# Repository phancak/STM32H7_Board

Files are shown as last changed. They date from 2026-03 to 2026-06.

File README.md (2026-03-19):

# STM32H7S3 High-Performance Modular Compute Platform

<div align="center">
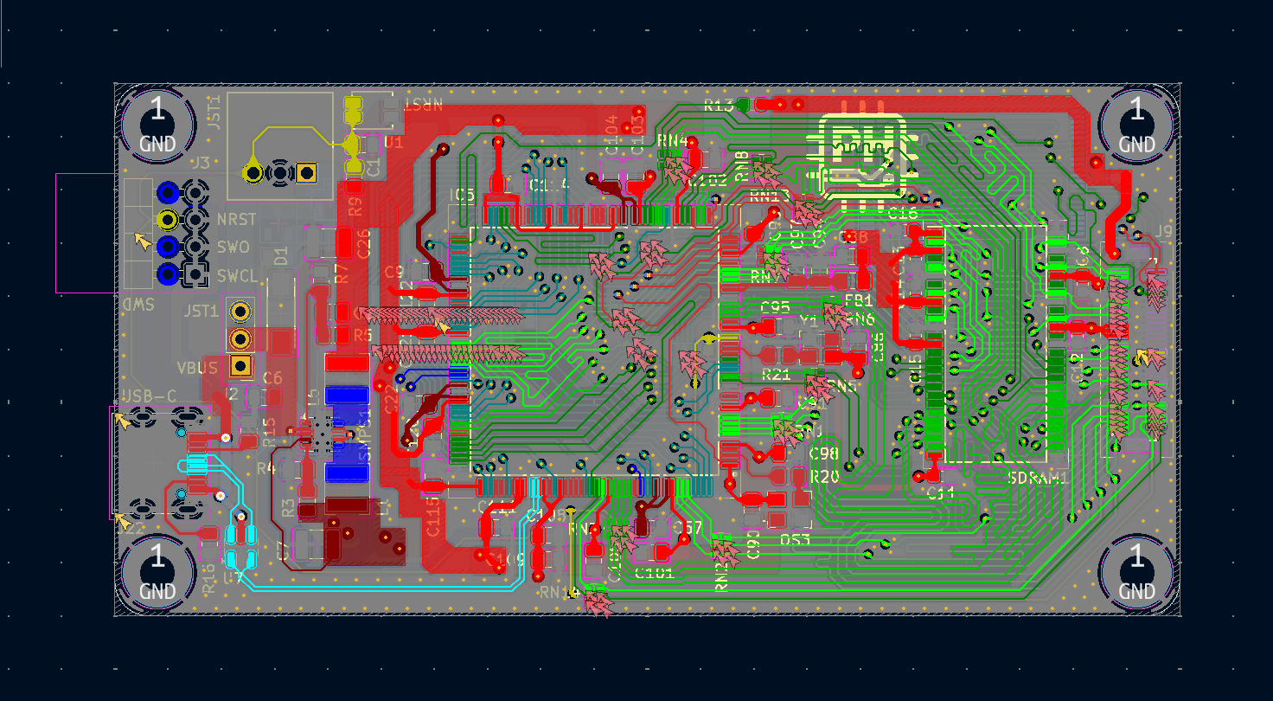
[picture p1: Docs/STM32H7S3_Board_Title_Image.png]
STM32H7S3 PCB 3D Render
  
  <br>
  <em>4-layer PCB diagram.</em>
</div>





## 📑 Quick Access
* [**📂 View Project Schematics (PDF)**](./Schematics/STM32H7_Board_Schematics.pdf)

## 📌 Project Overview
This project features a professional-grade, high-speed embedded system centered around the **STM32H7S3I8T6** (ARM Cortex-M7 running at 600 MHz). Developed as a post-graduate technical showcase, this board demonstrates proficiency in high-speed digital design, complex memory interfacing (SDRAM/NAND), and modular system architecture.

The platform is designed to serve as a high-bandwidth "Main Compute Module" that interfaces with expansion boards via a variety of industrial-standard protocols (PSSI, I2S, I2C, SPI, UART).

## 🛠 Technical Specifications

### Core Processing & Memory
* **MCU:** STM32H7S3I8T6 (600 MHz, 1MB SRAM, advanced security and graphics acceleration).
* **SDRAM:** 256 Mbit (IS42S83200J) @ 166 MHz — utilized for high-speed frame buffering and large-scale data processing.
* **NAND Flash:** 2 Gbit (MT29F2G08) — providing robust, non-volatile storage for OS and data logging.

### Connectivity & Expansion
* **PSSI (Parallel Synchronous Slave Interface):** Dedicated high-speed parallel bus for camera or FPGA data acquisition.
* **Audio (I2S):** High-fidelity audio interface with dedicated Master Clock (MCK) routing.
* **USB-C OTG:** High-speed (480 Mbps) data support with integrated UCPD (USB-C Power Delivery) logic.
* **Peripheral Bus:** Fully broken-out I2C, SPI, and UART headers for modular hardware stacking.

## 🚀 Engineering Design Highlights

### 1. High-Speed Signal Integrity (SI)
* **4-Layer Stackup:** Designed with a dedicated Ground plane (L2) and Power plane (L3) to provide a stable reference and minimize return path inductance.
* **Impedance Control:** Managed 90Ω differential pairs for USB High-Speed and 50Ω single-ended traces for memory clocks.
* **Memory Routing:** Implemented length-matching and fly-by/star topology considerations for the SDRAM address and data bus to meet strict setup and hold time requirements at 166 MHz.

### 2. Power Delivery Network (PDN)
* **Core Stability:** Designed for the 600 MHz switching transients of the Cortex-M7 using low-ESR ceramic decoupling arrays.
* **Via Stitching:** Utilized parallel via strategies (e.g., dual 0.3mm vias) for high-current power paths to minimize IR drop and parasitic inductance.

### 3. Hardware Robustness
* **ESD Protection:** Integrated low-capacitance TVS diode arrays on USB-C lines to protect sensitive MCU transceivers.
* **Signal Conditioning:** Series termination resistors on high-speed clocks (MCK, CK) and proper pull-up configurations for Open-Drain lines (NAND_RB).

## 🔬 Testing & Validation Plan

To ensure the reliability of a 600 MHz system, the following hardware validation protocols were implemented:

### 1. Signal Integrity (SI) Verification
Using a high-bandwidth digital oscilloscope (2 GHz+), the following critical signals are probed to verify timing margins and signal quality:
* **SDRAM Clock (166 MHz):** Measured for overshoot, undershoot, and rise/fall times ($t_R/t_F$) to ensure compliance with the IS42S83200J datasheet. 
* **Eye Diagram Analysis:** Performed on the USB High-Speed (480 Mbps) differential pairs to validate the $90\Omega$ impedance matching and ensure zero bit errors.
* **Clock Jitter:** Measured the stability of the I2S Master Clock (MCK) to prevent phase noise in audio reconstruction.

### 2. Power Integrity (PI) & Thermal Analysis
* **DC Load Testing:** Verified the 3.3V and 1.1V rails under maximum CPU/SDRAM load to ensure the IR drop across the power plane remains within $\pm 3\%$.
* **Transient Response:** Observed the $V_{CORE}$ rail during high-frequency switching to validate the effectiveness of the decoupling capacitor network.
* **Thermal Imaging:** Monitored the STM32H7S3 and SDRAM during continuous burst transfers to identify potential hotspots on the 4-layer stackup.

### 3. Memory Interface Stress Testing
* **MemTest86-style Routines:** Implemented custom firmware to perform pseudo-random pattern writes/reads across the entire 256 Mbit SDRAM space to check for bit-flip errors caused by crosstalk or timing skew.
* **NAND Bad Block Management:** Validated the ECC (Error Correction Code) and wear-leveling logic within the MT29F2G08 driver.

## 🛠 Skills Demonstrated
* **Hardware:** High-speed PCB design (Altium/KiCad), Differential Pair Routing, PDN Optimization, ESD/EMI protection.
* **Firmware:** C/C++, STM32 CubeHAL, Memory Management Units (MMU), DMA configuration.
* **Tools:** Digital Oscilloscopes, Logic Analyzers, Spectrum Analyzers.

## 📂 Repository Structure
* `/Hardware`: Schematic (PDF/Source), PCB Layout, and Layer Stackup definitions.
* `/Firmware`: BSP (Board Support Package), memory initialization code, and driver implementations.
* `/Docs`: Power budget analysis and timing margin calculations.

## 🎓 About the Author
I am a recent **Electrical Engineering graduate from the University of British Columbia (UBC)**. This project represents my ability to transition theoretical academic knowledge into a complex, manufacturable high-speed digital system.

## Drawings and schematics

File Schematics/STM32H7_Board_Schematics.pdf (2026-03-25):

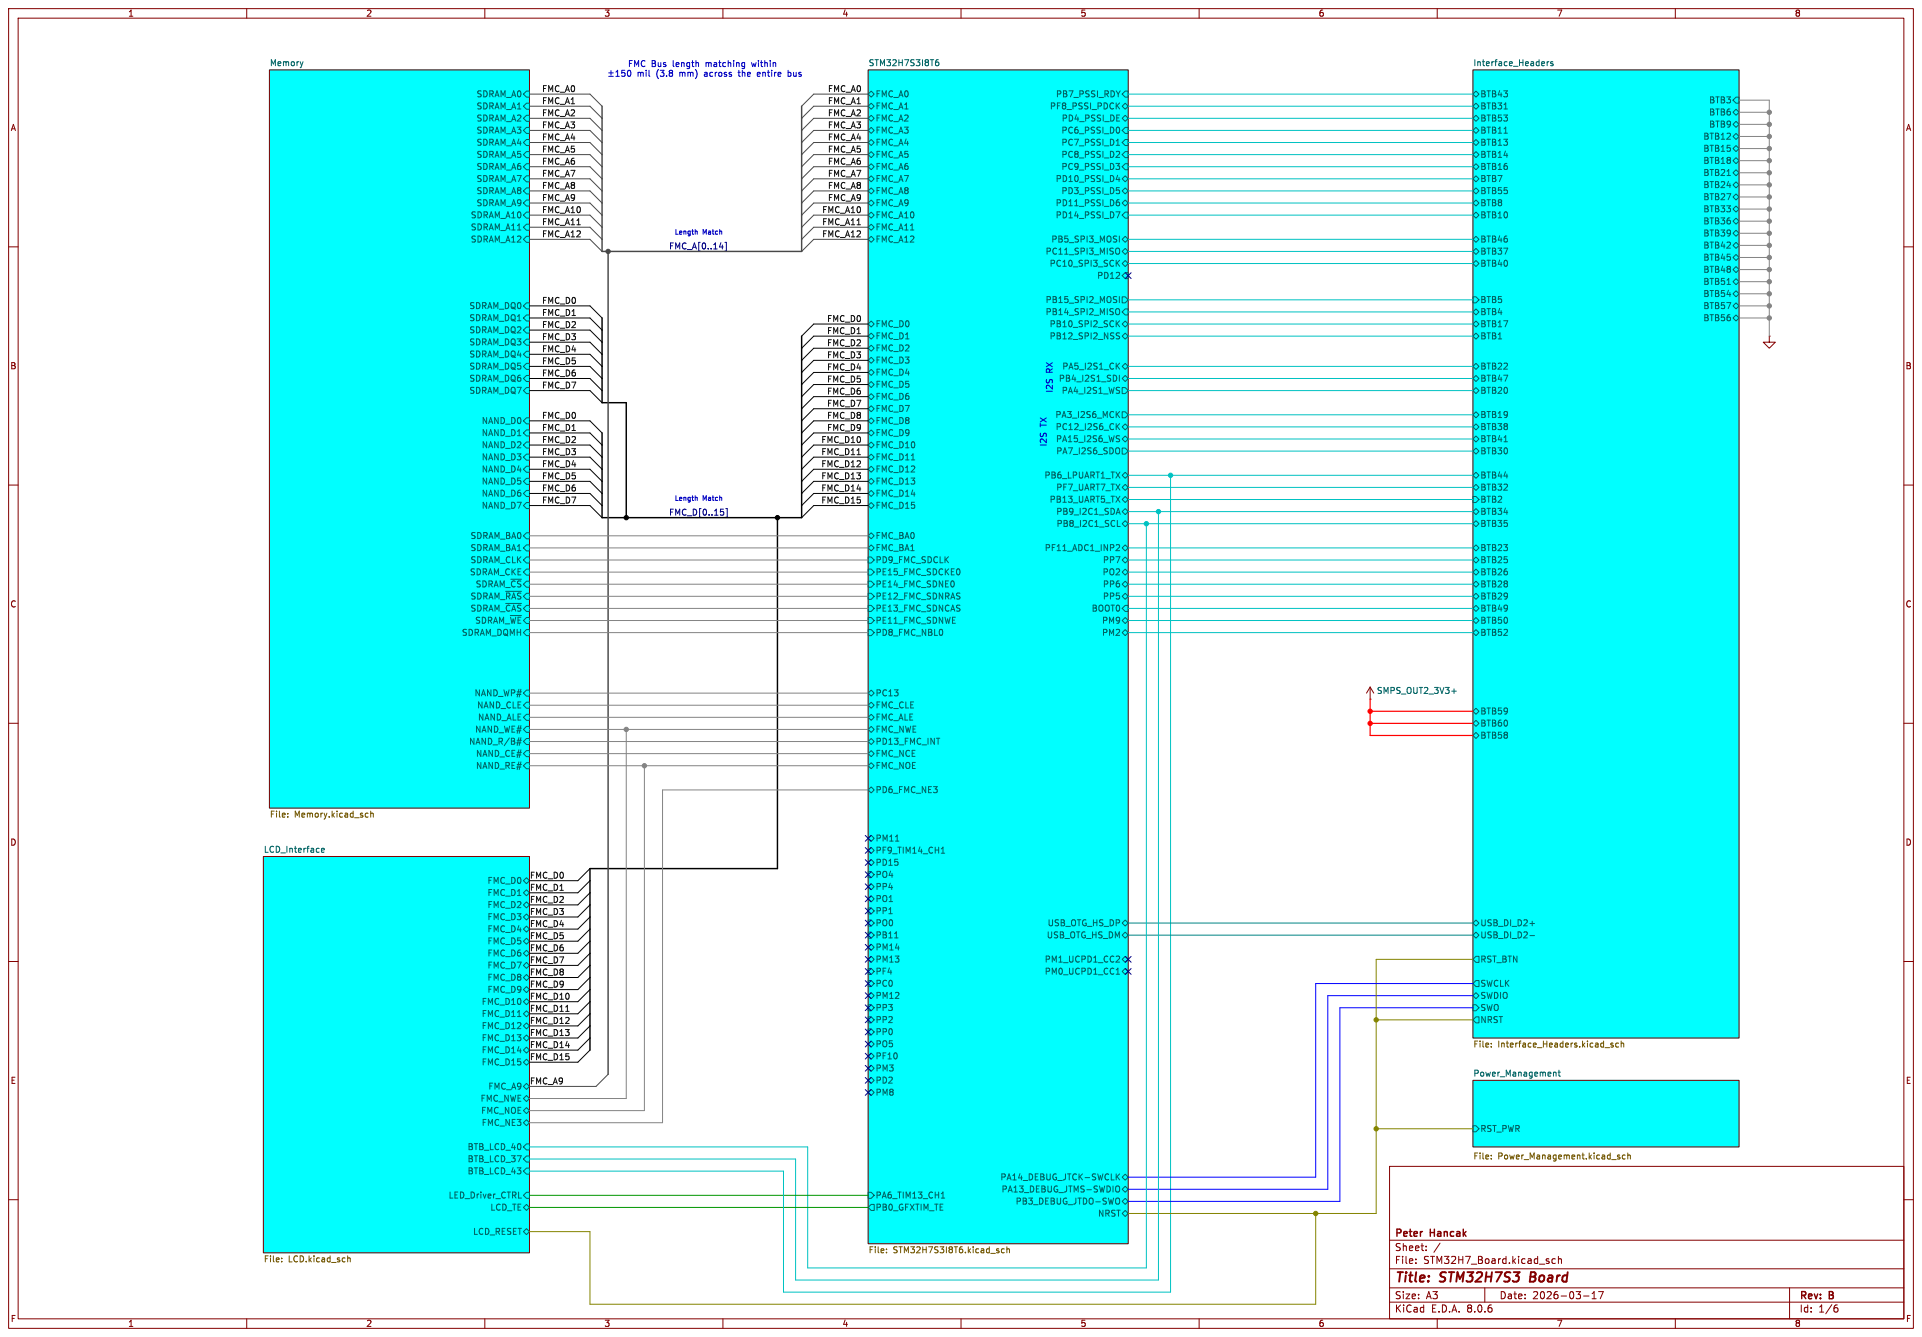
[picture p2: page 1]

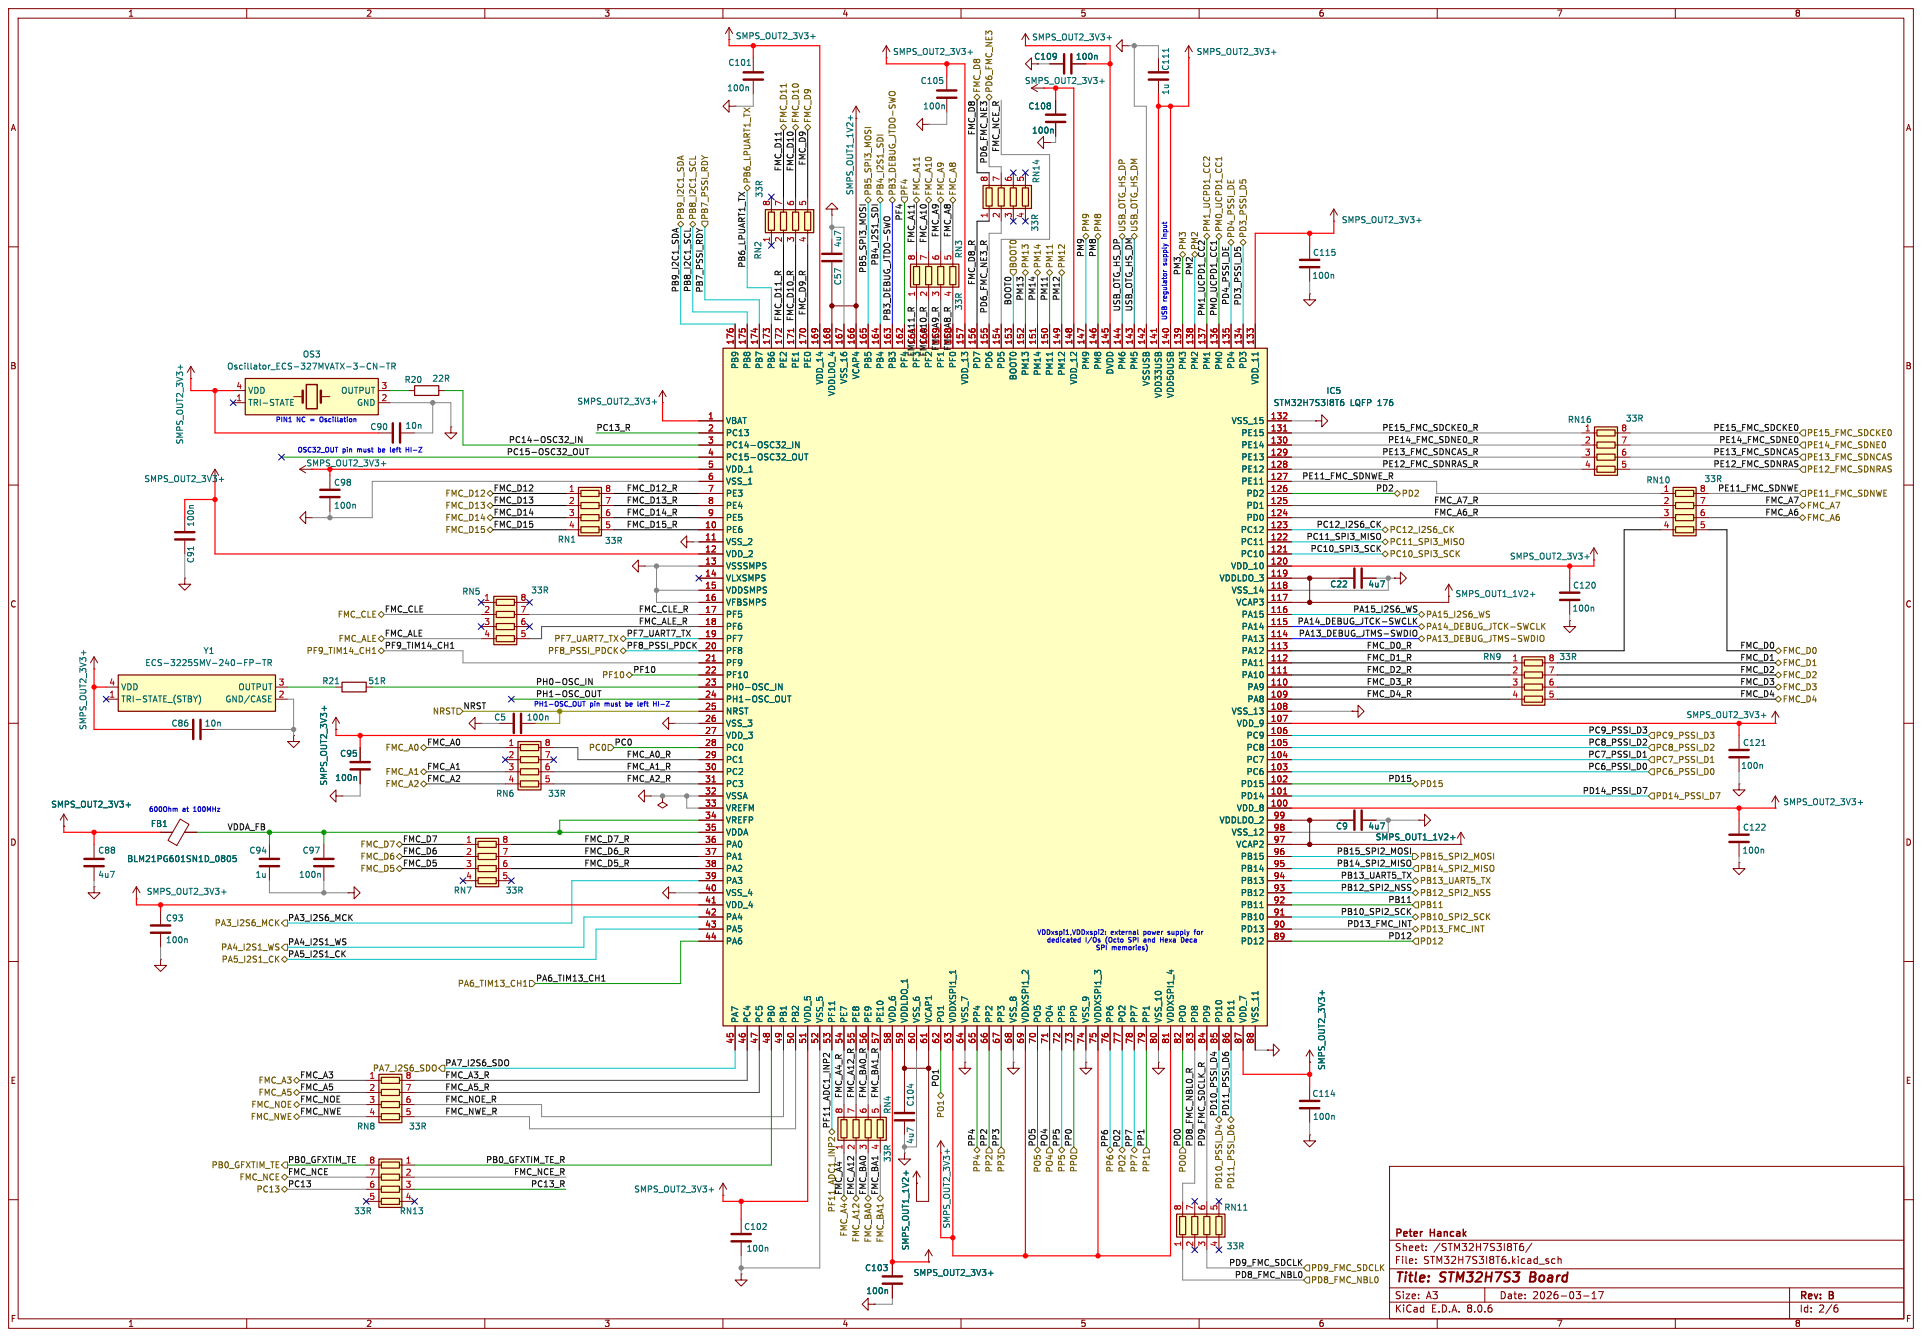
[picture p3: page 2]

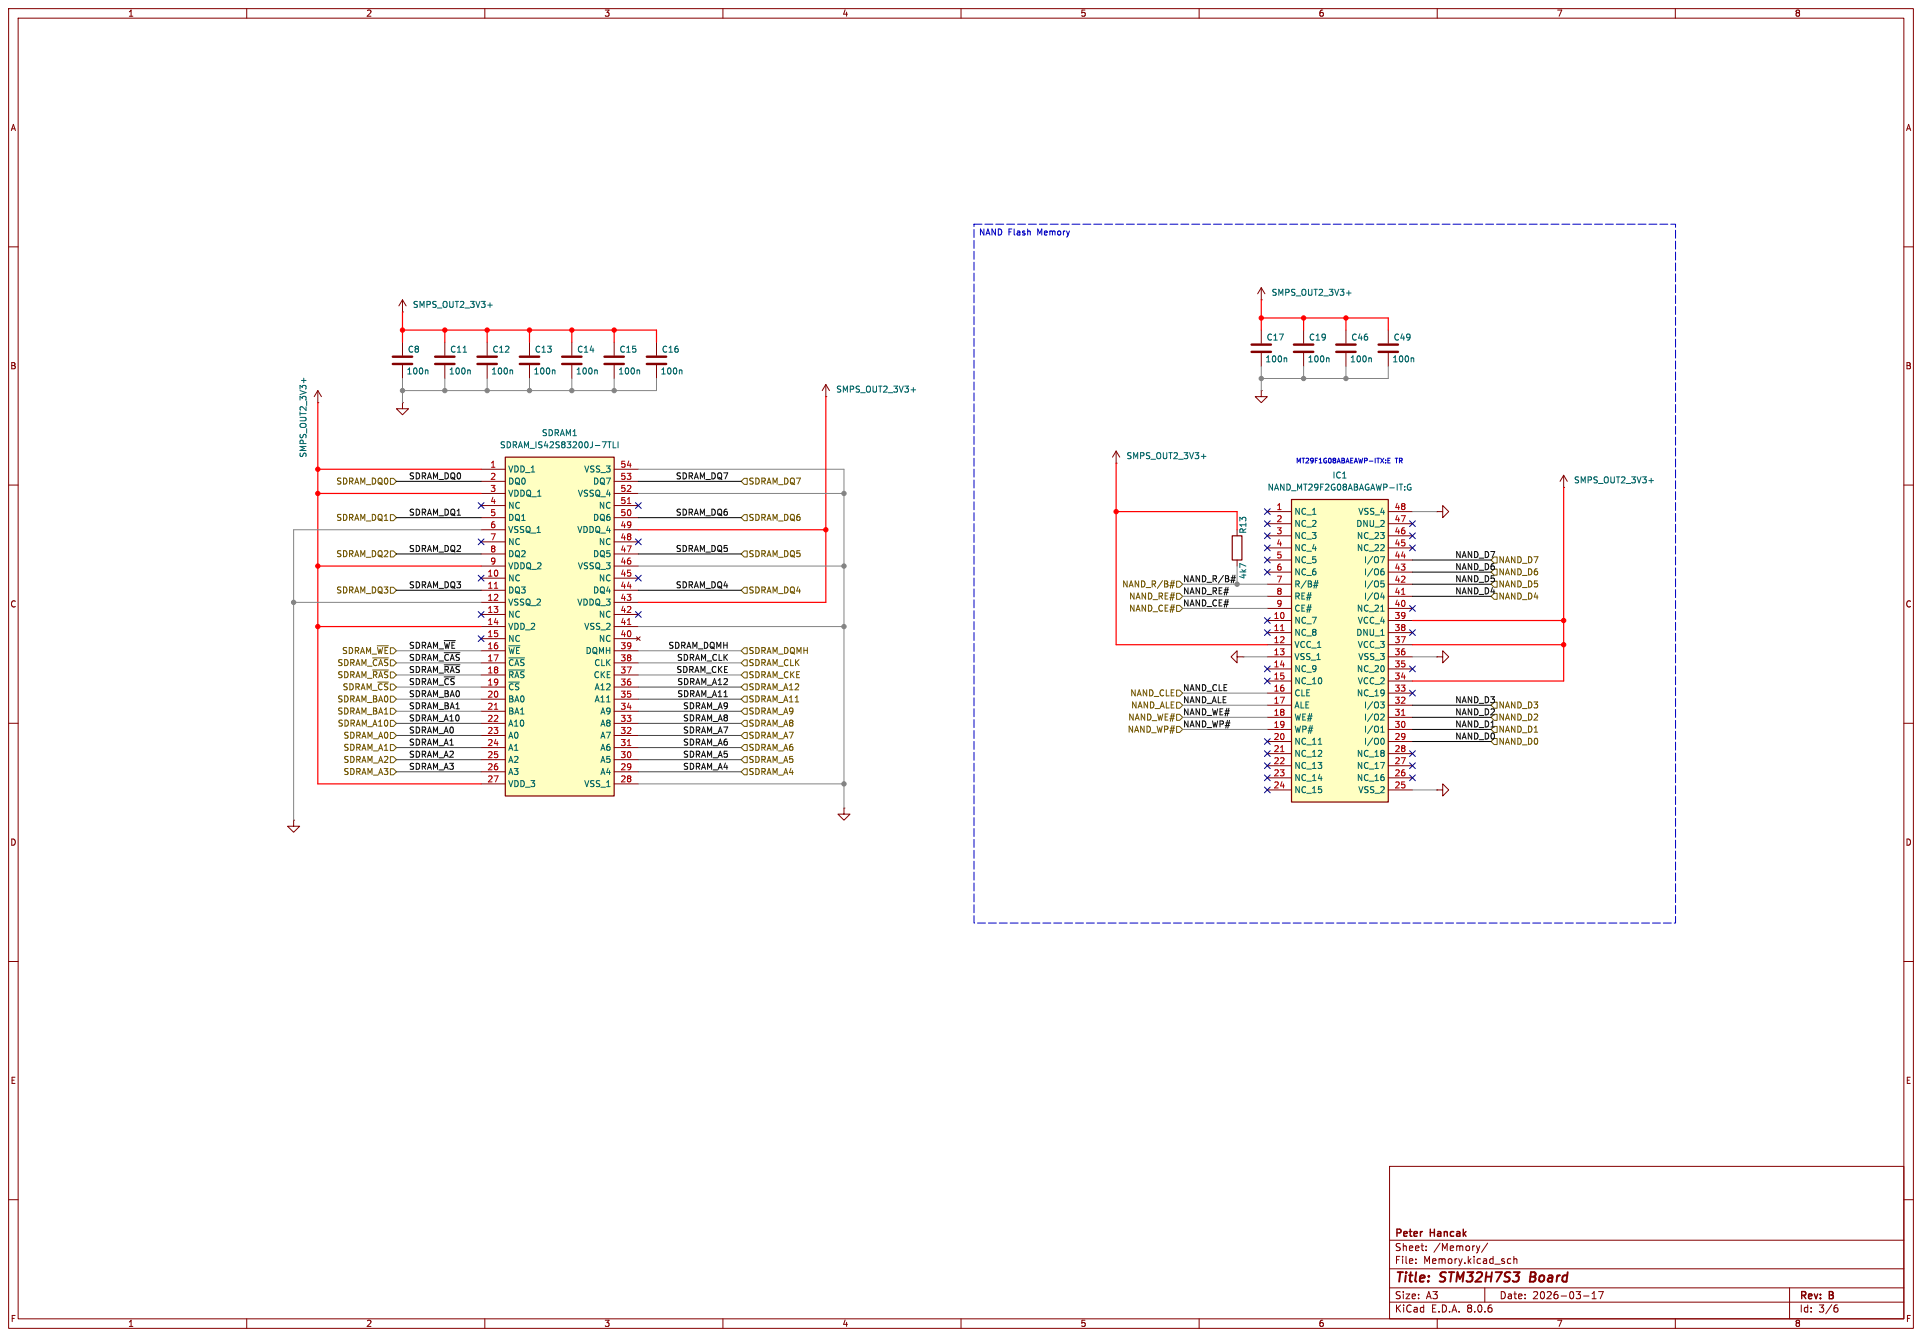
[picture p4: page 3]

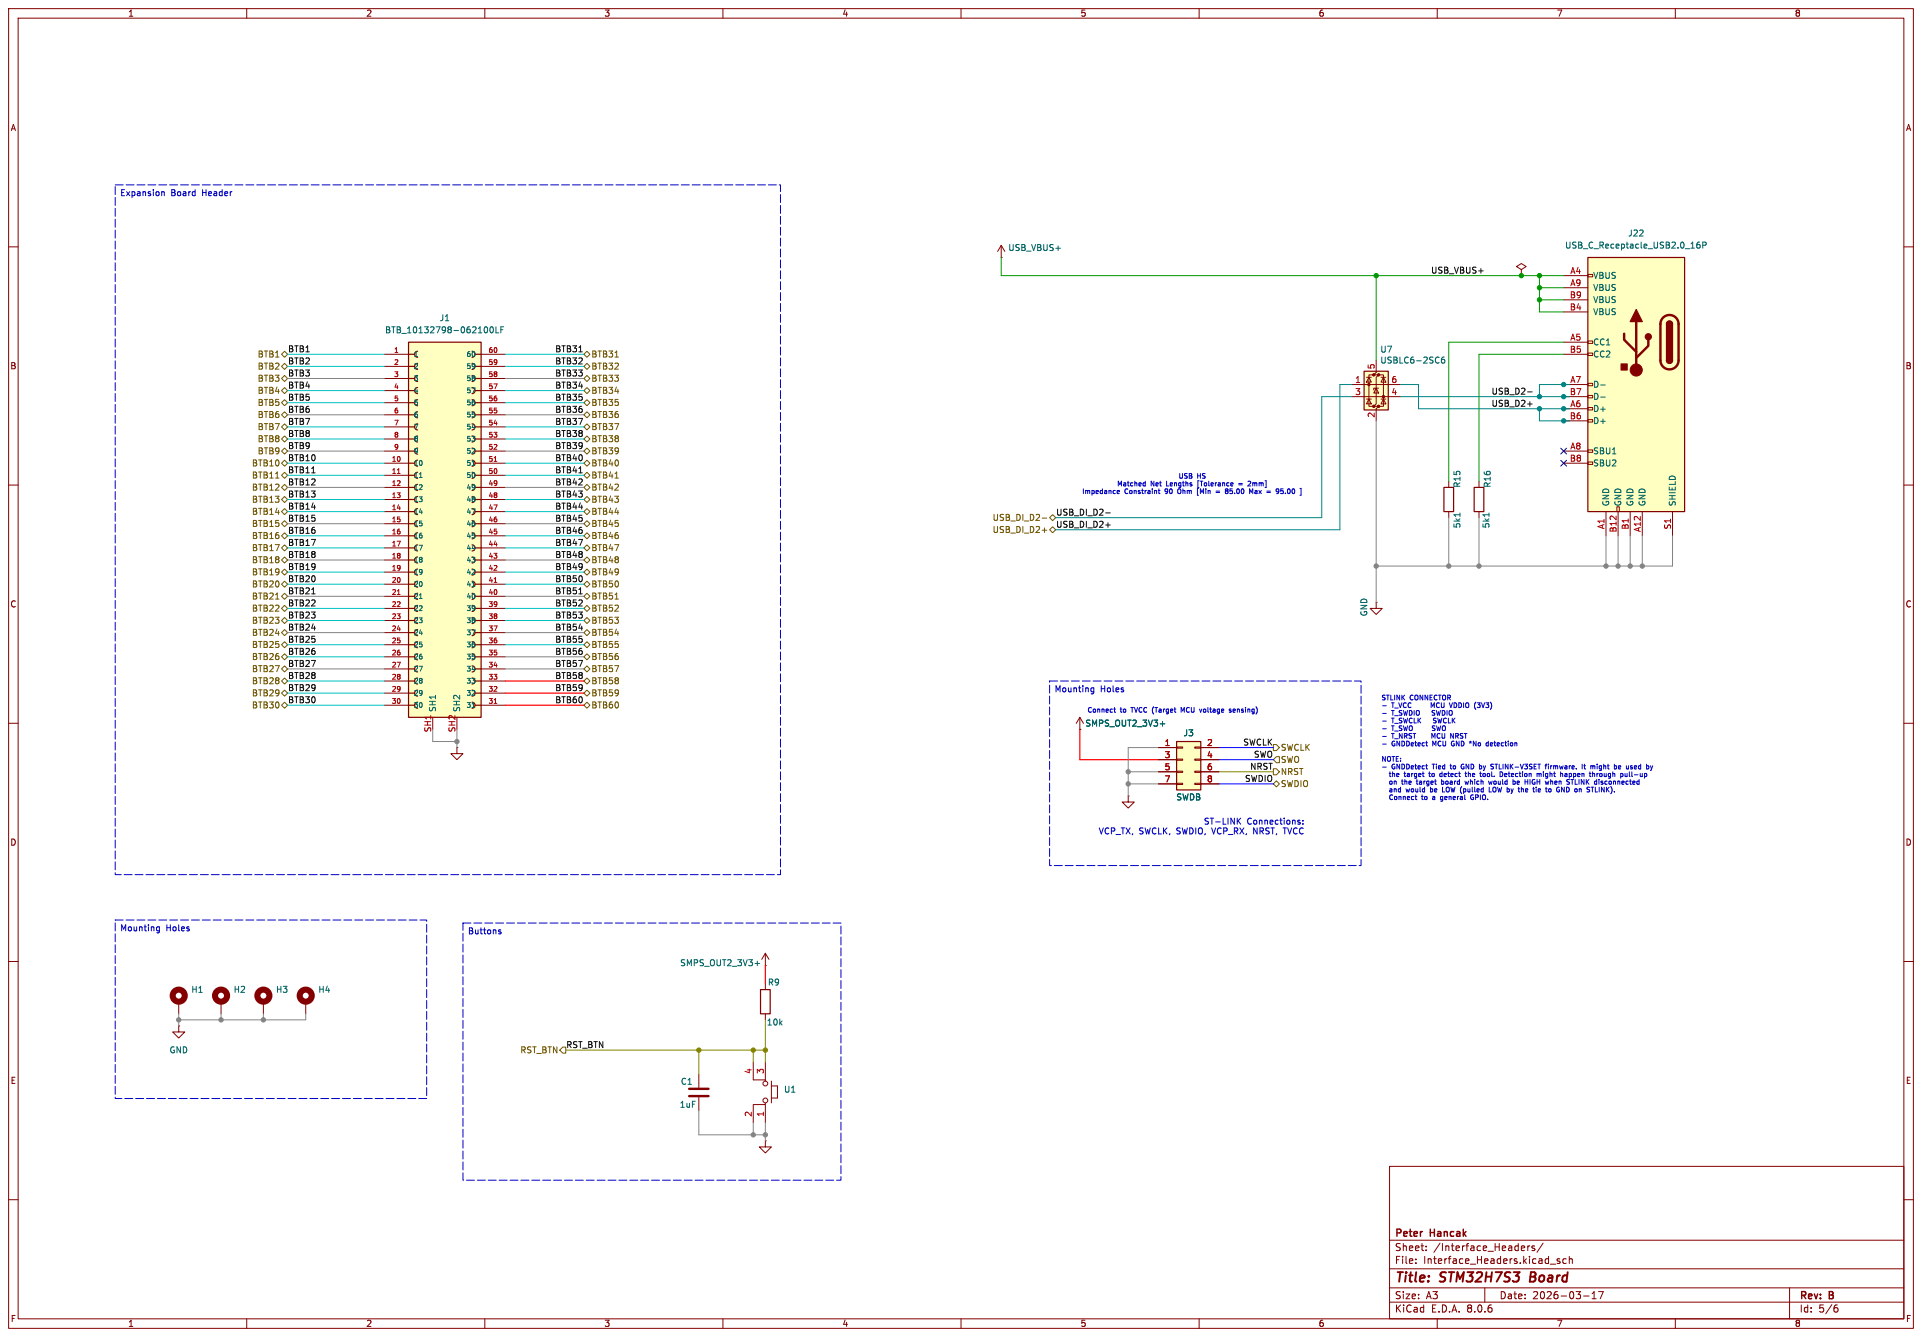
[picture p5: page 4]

on the target board which would be HIGH when STLINK disconnected

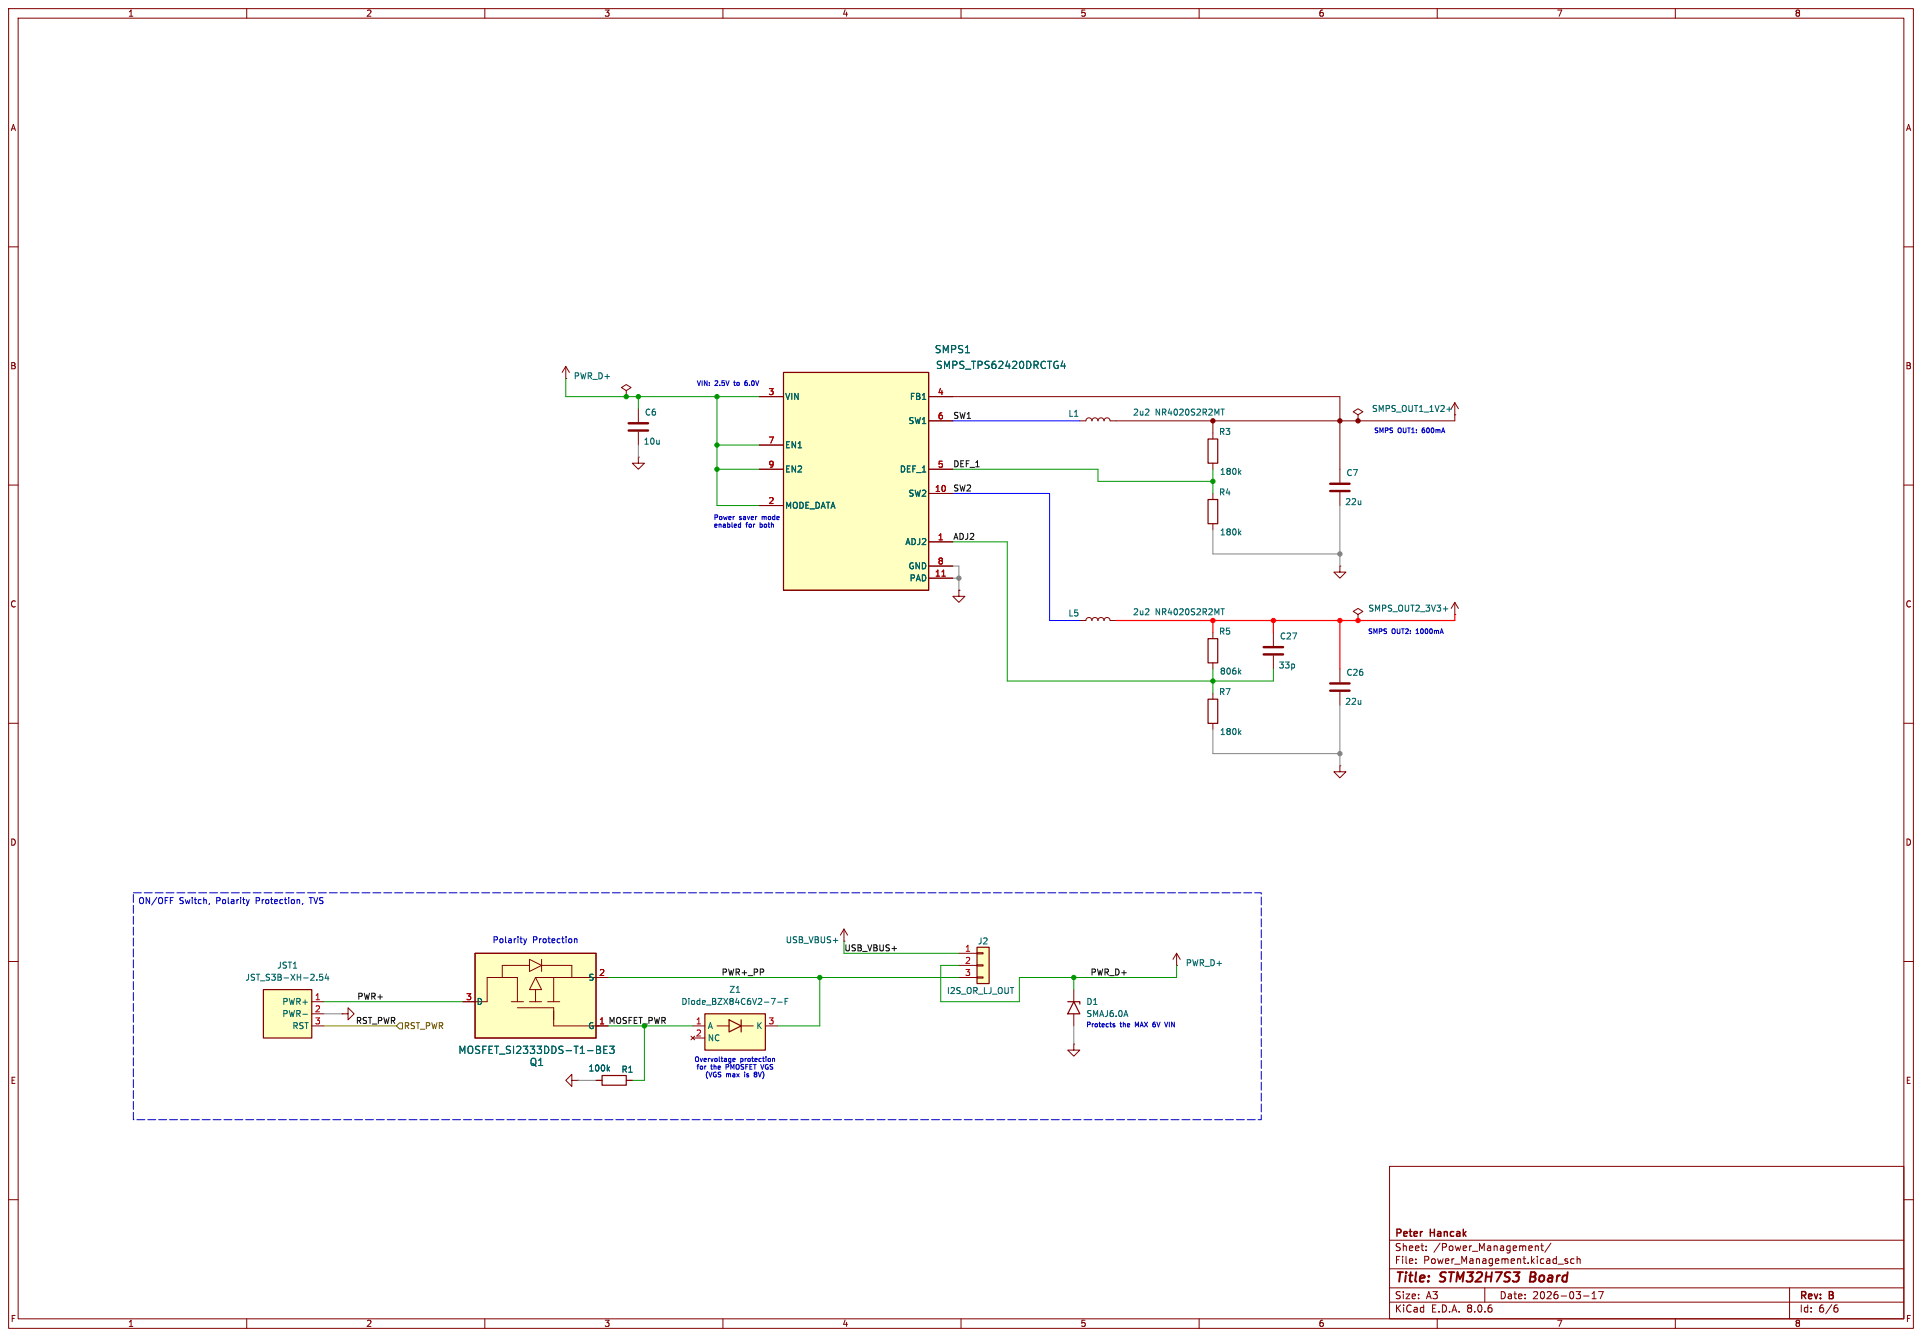
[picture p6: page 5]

for the PMOSFET VGS

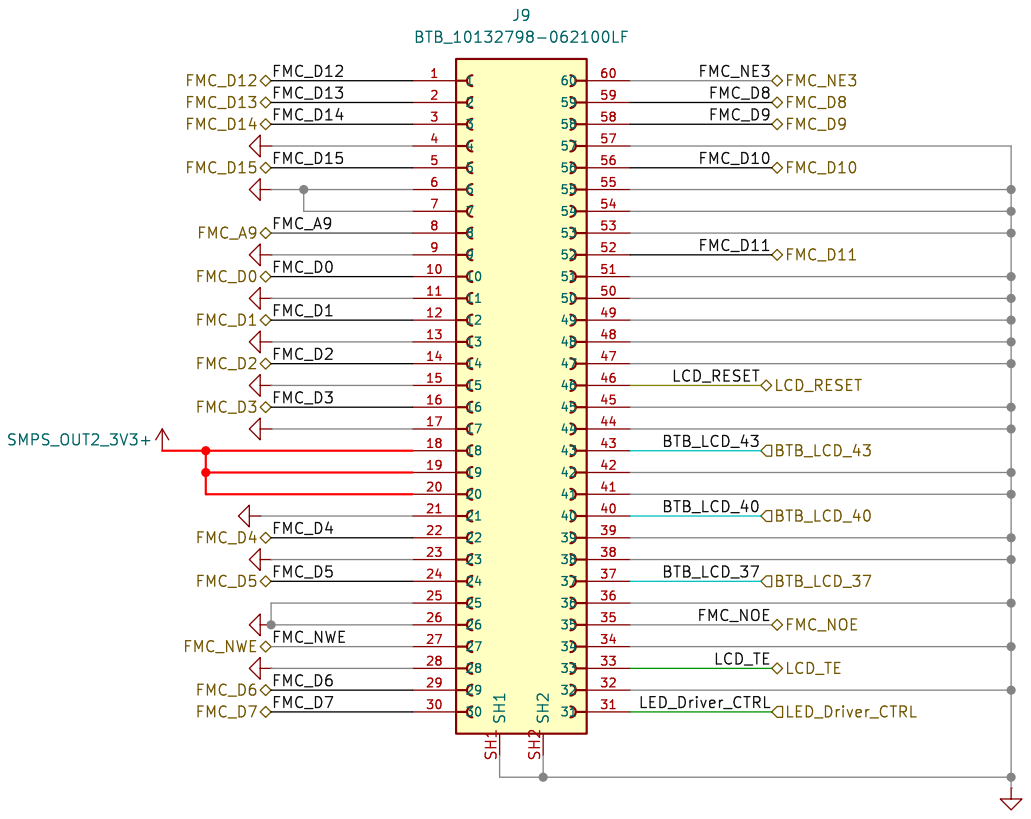
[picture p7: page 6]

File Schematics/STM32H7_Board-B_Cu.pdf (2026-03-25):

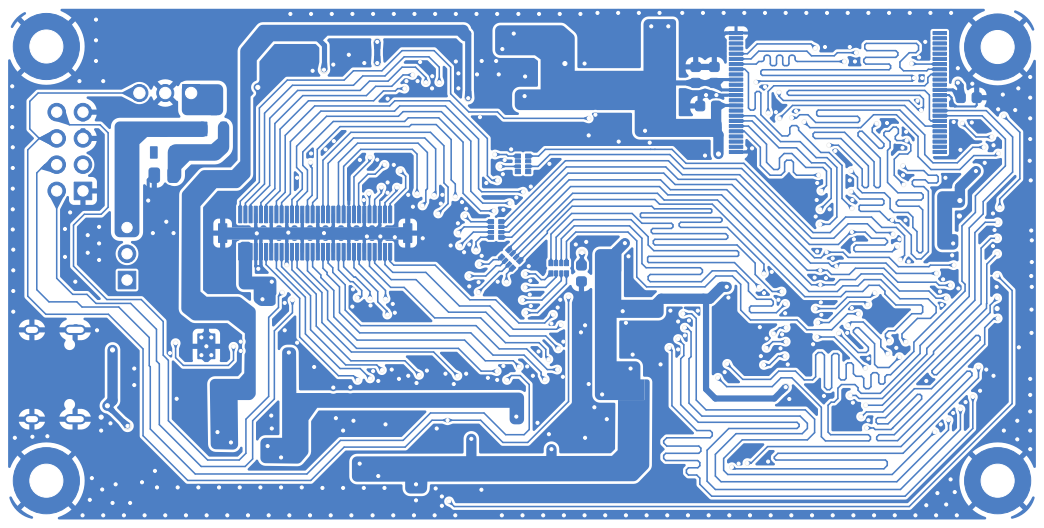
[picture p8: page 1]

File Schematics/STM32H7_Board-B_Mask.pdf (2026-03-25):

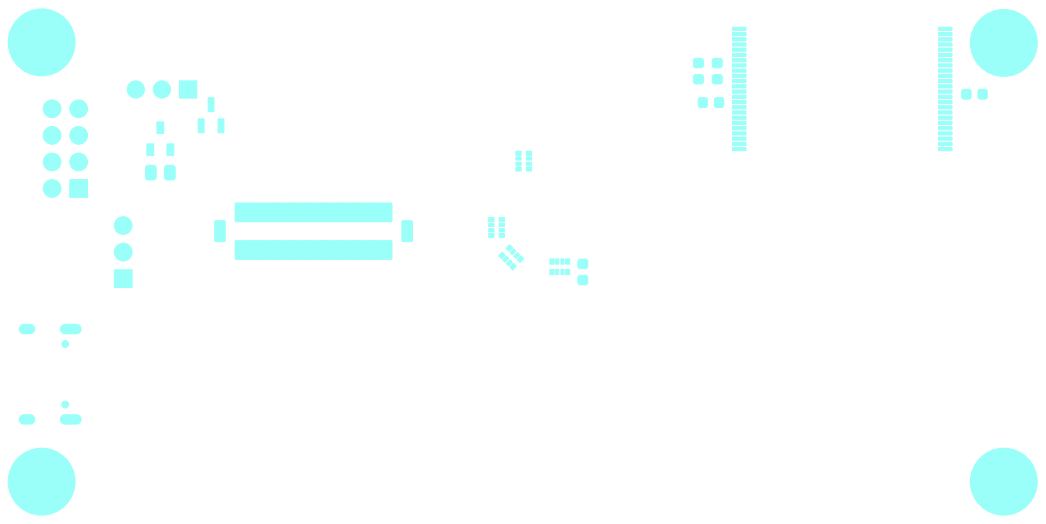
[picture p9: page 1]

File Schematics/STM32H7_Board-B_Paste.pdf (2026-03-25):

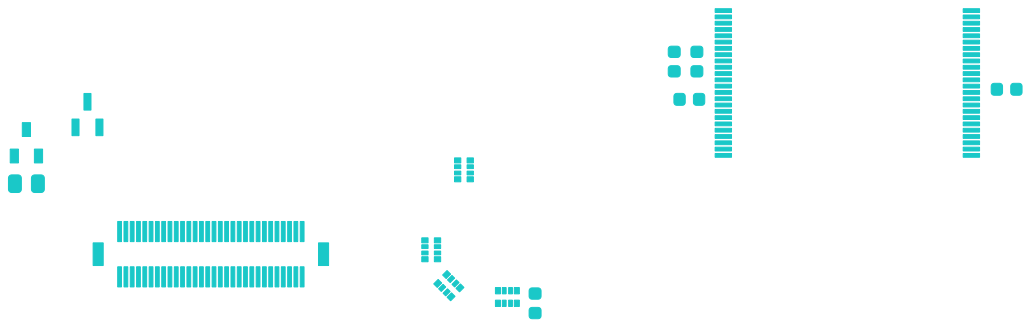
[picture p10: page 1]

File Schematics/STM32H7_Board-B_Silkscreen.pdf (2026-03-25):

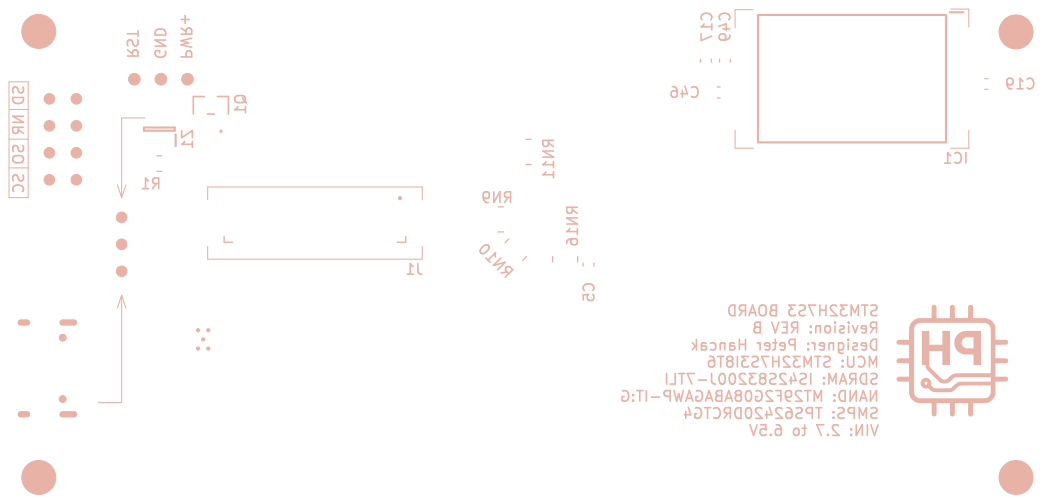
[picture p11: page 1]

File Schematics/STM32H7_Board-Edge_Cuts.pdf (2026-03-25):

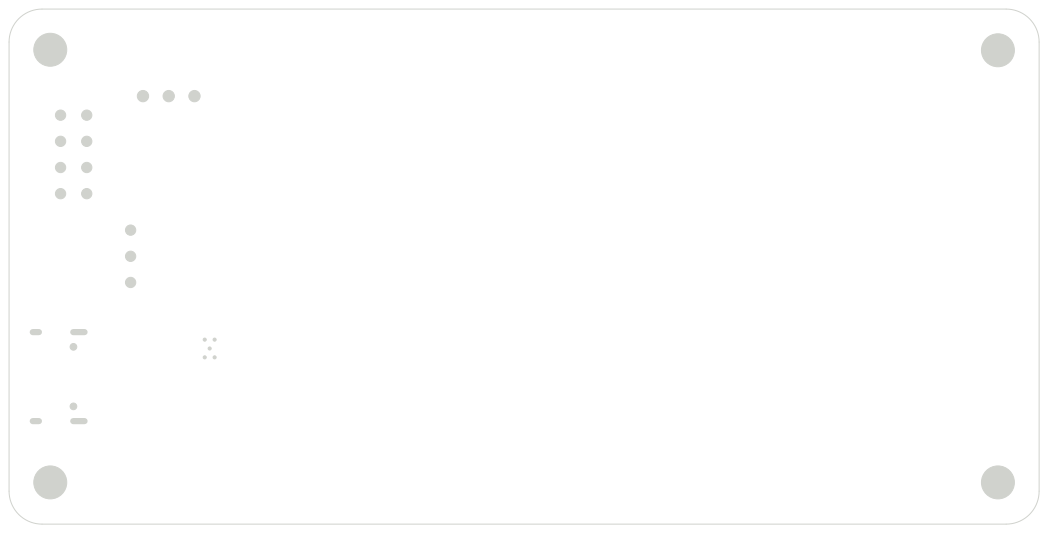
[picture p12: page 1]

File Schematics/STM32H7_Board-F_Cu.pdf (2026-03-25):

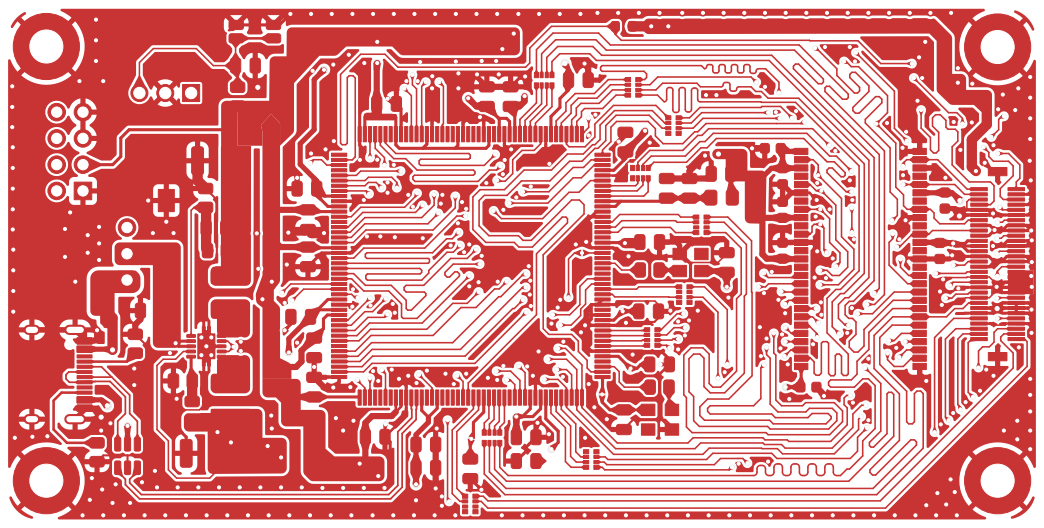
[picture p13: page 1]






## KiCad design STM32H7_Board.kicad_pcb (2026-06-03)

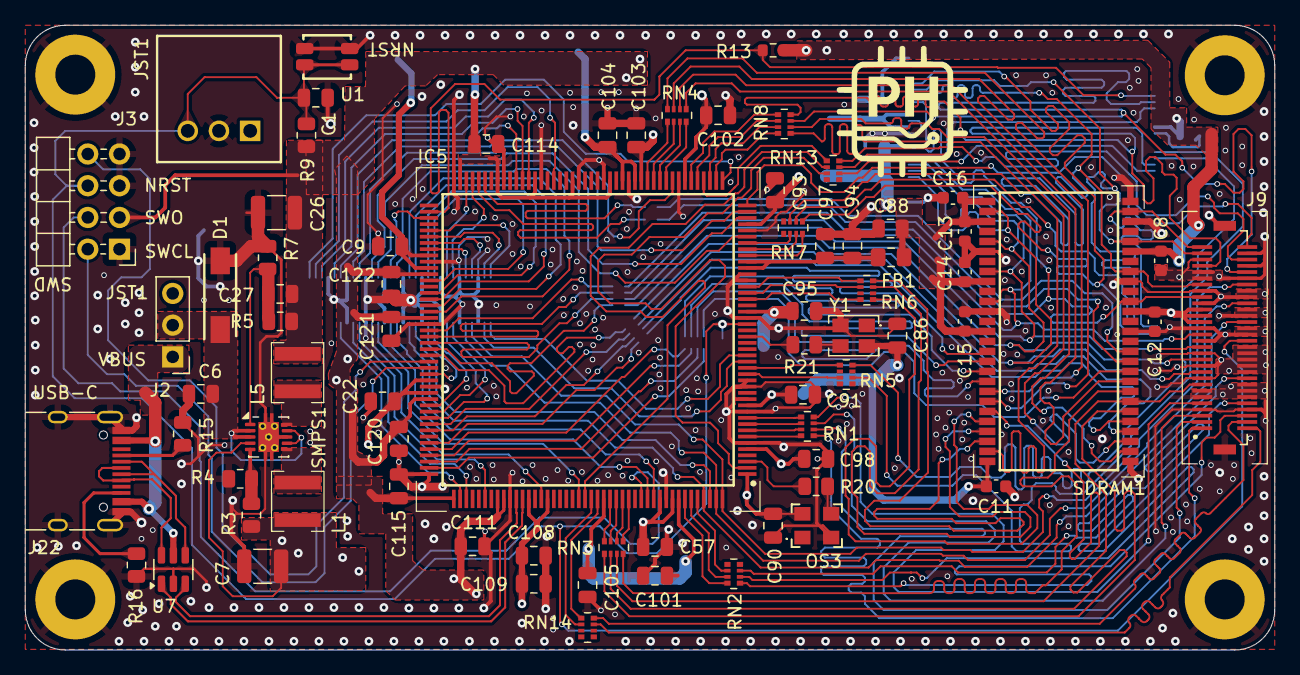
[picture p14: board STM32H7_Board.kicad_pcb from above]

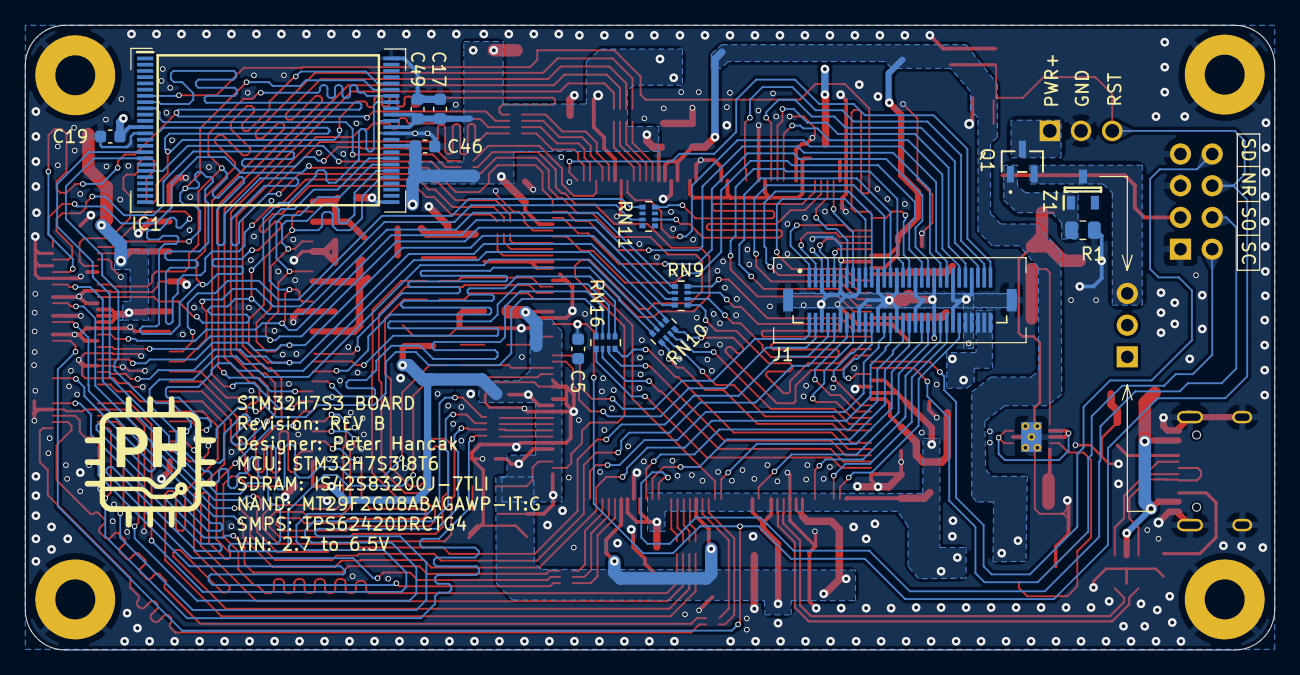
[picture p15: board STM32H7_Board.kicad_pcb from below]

Board: 4 copper layers, 100.0 x 50.0 mm, 91 parts (14 on the bottom side), 159 nets.

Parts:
C1: 1uF; C_0805_2012Metric
C5, C8, C11, C12, C13, C14, C15, C16, C17, C19, C46, C49: 100n; C_0603_1608Metric
C6: 10u; C_0805_2012Metric
C7, C26: 22u; C_1210_3225Metric
C9, C22, C57, C88, C104: 4u7; C_0805_2012Metric
C27: 33p; C_0805_2012Metric
C86, C90: 10n; C_0805_2012Metric
C91, C93, C95, C97, C98, C101, C102, C103, C105, C108, C109, C114, C115, C120, C121, C122: 100n; C_0805_2012Metric
C94, C111: 1u; C_0805_2012Metric
D1: SMAJ6.0A; DO-214AC-2
FB1: BLM21PG601SN1D_0805; C_0805_2012Metric_Pad1.18x1.45mm_HandSolder
H1, H2, H3, H4: MountingHole_Pad; MountingHole_3.2mm_M3_Pad
IC1: NAND_MX30LF1G18AC-TI; NAND_MT29F1G08ABAEAWP-IT_E_TR_SOP50P2000X120-48N
IC5: STM32H7S3I8T6 LQFP 176; QFP50P2600X2600X160-176N
J1, J9: BTB_10132798-062100LF; BTB_AMPHENOL_10132798-062100LF
J2: I2S_OR_LJ_OUT; PinHeader_1x03_P2.54mm_Vertical
J3: SWDB; PinHeader_2x04_P2.54mm_Horizontal
J22: USB_C_Receptacle_USB2.0_16P; USB_C_Receptacle_HRO_TYPE-C-31-M-12
JST1: JST_S3B-XH-2.54; JST_S3B-XH-SHDRRA3W64P0X250_1X3_990X1150X610P
L1: 2u2 NR4020S2R2MT; L_NR4020S2R2MT
L5: 3u3 CPN4020H3R3MT; L_NR4020S2R2MT
OS3: Oscillator_ECS-327MVATX-3-CN-TR; Oscillator_ECS327MVATX3CNTR
Q1: MOSFET_SI2333DDS-T1-BE3; MOSFET_ SI2333DDS_SOT_DS-T1-BE3_VIS
R1: 100k; R_0805_2012Metric
R3, R4, R7: 180k; R_0805_2012Metric
R5: 806k; R_0805_2012Metric
R9: 10k; R_0805_2012Metric_1
R13: 4k7; R_0603_1608Metric
R15, R16: 5k1; R_0805_2012Metric
R20: 22R; R_0805_2012Metric_1
R21: 51R; R_0805_2012Metric_1
RN1, RN2, RN3, RN4, RN5, RN6, RN7, RN8, RN9, RN10, RN11, RN13, RN14, RN16: 33R; R_Array_Convex_4x0402
SDRAM1: SDRAM_AS4C32M8SA-7TCN; SDRAM_IS42S16320F-6TL
SMPS1: SMPS_TPS62420DRCT; VSON-10-1EP_3x3mm_P0.5mm_EP1.65x2.4mm_ThermalVias
U1: Button_SKSCLCE010
U7: USBLC6-2SC6; SOT-23-6
Y1: ECS-3225SMVQ-240-DS-TR; Oscillator_ASE50000MHZLRT
Z1: Diode_BZX84C6V2-7-F; Diode_BZX84C6V2_SOT96P240X110-3N

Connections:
/FMC_A0: RN6.1 (R1.1), SDRAM1.23 (A0)
/FMC_A1: RN6.3 (R3.1), SDRAM1.24 (A1)
/FMC_A2: RN6.4 (R4.1), SDRAM1.25 (A2)
/FMC_A3: RN8.1 (R1.1), SDRAM1.26 (A3)
/FMC_A4: RN4.1 (R1.1), SDRAM1.29 (A4)
/FMC_A5: RN8.2 (R2.1), SDRAM1.30 (A5)
/FMC_A6: RN10.6 (R3.2), SDRAM1.31 (A6)
/FMC_A7: RN10.7 (R2.2), SDRAM1.32 (A7)
/FMC_A8: RN3.5 (R4.2), SDRAM1.33 (A8)
/FMC_A9: J9.8, RN3.6 (R3.2), SDRAM1.34 (A9)
/FMC_A10: RN3.7 (R2.2), SDRAM1.22 (A10)
/FMC_A11: RN3.8 (R1.2), SDRAM1.35 (A11)
/FMC_A12: RN4.2 (R2.1), SDRAM1.36 (A12)
/FMC_D0: IC1.29 (I/O0), J9.10, RN10.5 (R4.2), SDRAM1.2 (DQ0)
/FMC_D1: IC1.30 (I/O1), J9.12, RN9.8 (R1.2), SDRAM1.5 (DQ1)
/FMC_D2: IC1.31 (I/O2), J9.14, RN9.7 (R2.2), SDRAM1.8 (DQ2)
/FMC_D3: IC1.32 (I/O3), J9.16, RN9.6 (R3.2), SDRAM1.11 (DQ3)
/FMC_D4: IC1.41 (I/O4), J9.22, RN9.5 (R4.2), SDRAM1.44 (DQ4)
/FMC_D5: IC1.42 (I/O5), J9.24, RN7.3 (R3.1), SDRAM1.47 (DQ5)
/FMC_D6: IC1.43 (I/O6), J9.29, RN7.2 (R2.1), SDRAM1.50 (DQ6)
/FMC_D7: IC1.44 (I/O7), J9.30, RN7.1 (R1.1), SDRAM1.53 (DQ7)
/FMC_D8: J9.59, RN14.8 (R1.2)
/FMC_D9: J9.58, RN2.5 (R4.2)
/FMC_D10: J9.56, RN2.6 (R3.2)
/FMC_D11: J9.52, RN2.7 (R2.2)
/FMC_D12: J9.1, RN1.1 (R1.1)
/FMC_D13: J9.2, RN1.2 (R2.1)
/FMC_D14: J9.3, RN1.3 (R3.1)
/FMC_D15: J9.5, RN1.4 (R4.1)
/Interface_Headers/BTB1: IC5.93 (PB12), J1.1
/Interface_Headers/BTB2: IC5.94 (PB13), J1.2
/Interface_Headers/BTB4: IC5.95 (PB14), J1.4
/Interface_Headers/BTB5: IC5.96 (PB15), J1.5
/Interface_Headers/BTB7: IC5.85 (PD10), J1.7
/Interface_Headers/BTB8: IC5.86 (PD11), J1.8
/Interface_Headers/BTB10: IC5.101 (PD14), J1.10
/Interface_Headers/BTB11: IC5.103 (PC6), J1.11
/Interface_Headers/BTB13: IC5.104 (PC7), J1.13
/Interface_Headers/BTB14: IC5.105 (PC8), J1.14
/Interface_Headers/BTB16: IC5.106 (PC9), J1.16
/Interface_Headers/BTB17: IC5.91 (PB10), J1.17
/Interface_Headers/BTB19: IC5.39 (PA3), J1.19
/Interface_Headers/BTB20: IC5.42 (PA4), J1.20
/Interface_Headers/BTB22: IC5.43 (PA5), J1.22
/Interface_Headers/BTB23: IC5.53 (PF11), J1.23
/Interface_Headers/BTB25: IC5.78 (PP7), J1.25
/Interface_Headers/BTB26: IC5.77 (PO2), J1.26
/Interface_Headers/BTB28: IC5.76 (PP6), J1.28
/Interface_Headers/BTB29: IC5.72 (PP5), J1.29
/Interface_Headers/BTB30: IC5.45 (PA7), J1.30
/Interface_Headers/BTB31: IC5.20 (PF8), J1.60
/Interface_Headers/BTB32: IC5.19 (PF7), J1.59
/Interface_Headers/BTB34: IC5.176 (PB9), J1.57, J9.37
/Interface_Headers/BTB35: IC5.175 (PB8), J1.56, J9.40
/Interface_Headers/BTB37: IC5.122 (PC11), J1.54
/Interface_Headers/BTB38: IC5.123 (PC12), J1.53
/Interface_Headers/BTB40: IC5.121 (PC10), J1.51
/Interface_Headers/BTB41: IC5.116 (PA15), J1.50
/Interface_Headers/BTB43: IC5.174 (PB7), J1.48
/Interface_Headers/BTB44: IC5.173 (PB6), J1.47, J9.43
/Interface_Headers/BTB46: IC5.165 (PB5), J1.45
/Interface_Headers/BTB47: IC5.164 (PB4), J1.44
/Interface_Headers/BTB49: IC5.153 (BOOT0), J1.42
/Interface_Headers/BTB50: IC5.147 (PM9), J1.41
/Interface_Headers/BTB52: IC5.138 (PM2), J1.39
/Interface_Headers/BTB53: IC5.135 (PD4), J1.38
/Interface_Headers/BTB55: IC5.134 (PD3), J1.36
/Interface_Headers/NRST: C1.2, C5.2, IC5.25 (NRST), J3.6, J9.46, JST1.3 (RST), R9.1, U1.3, U1.4
/Interface_Headers/SWCLK: IC5.115 (PA14), J3.2
/Interface_Headers/SWDIO: IC5.114 (PA13), J3.8
/Interface_Headers/SWO: IC5.163 (PB3), J3.4
/Interface_Headers/USB_D2+: J22.A6 (D+), J22.B6 (D+), U7.6 (I/O1)
/Interface_Headers/USB_D2-: J22.A7 (D-), J22.B7 (D-), U7.4 (I/O2)
/Interface_Headers/USB_DI_D2+: IC5.144 (PM6), U7.1 (I/O1)
/Interface_Headers/USB_DI_D2-: IC5.143 (PM5), U7.3 (I/O2)
/LCD_Interface/FMC_NE3: J9.60, RN14.7 (R2.2)
/LCD_Interface/FMC_NOE: IC1.8 (RE#), J9.35, RN8.3 (R3.1)
/LCD_Interface/FMC_NWE: IC1.18 (WE#), J9.27, RN8.4 (R4.1)
/LCD_Interface/LCD_TE: J9.33, RN13.8 (R1.2)
/LCD_Interface/LED_Driver_CTRL: IC5.44 (PA6), J9.31
/Memory/NAND_ALE: IC1.17 (ALE), RN5.4 (R4.1)
/Memory/NAND_CE#: IC1.9 (CE#), RN13.7 (R2.2)
/Memory/NAND_CLE: IC1.16 (CLE), RN5.2 (R2.1)
/Memory/NAND_R/B#: IC1.7 (R/B#), IC5.90 (PD13), R13.2
/Memory/NAND_WP#: IC1.19 (WP#), RN13.6 (R3.2)
/Memory/SDRAM_BA0: RN4.3 (R3.1), SDRAM1.20 (BA0)
/Memory/SDRAM_BA1: RN4.4 (R4.1), SDRAM1.21 (BA1)
/Memory/SDRAM_CKE: RN16.8 (R1.2), SDRAM1.37 (CKE)
/Memory/SDRAM_CLK: RN11.3 (R3.1), SDRAM1.38 (CLK)
/Memory/SDRAM_DQMH: RN11.1 (R1.1), SDRAM1.39 (DQMH)
/Memory/SDRAM_~CAS: RN16.6 (R3.2), SDRAM1.17 (~CAS)
/Memory/SDRAM_~CS: RN16.7 (R2.2), SDRAM1.19 (~CS)
/Memory/SDRAM_~RAS: RN16.5 (R4.2), SDRAM1.18 (~RAS)
/Memory/SDRAM_~WE: RN10.8 (R1.2), SDRAM1.16 (~WE)
/Power_Management/ADJ2: C27.1, R5.2, R7.1, SMPS1.1 (ADJ2)
/Power_Management/DEF_1: R3.2, R4.1, SMPS1.5 (DEF_1)
/Power_Management/MOSFET_PWR: Q1.1 (G), R1.1, Z1.1 (A)
/Power_Management/PWR+: JST1.1 (PWR+), Q1.3 (D)
/Power_Management/PWR+_PP: J2.3, Q1.2 (S), Z1.3 (K)
/Power_Management/SW1: L1.1, SMPS1.6 (SW1)
/Power_Management/SW2: L5.1, SMPS1.10 (SW2)
/STM32H7S3I8T6/FMC_A0_R: IC5.29 (PC1), RN6.8 (R1.2)
/STM32H7S3I8T6/FMC_A1_R: IC5.30 (PC2), RN6.6 (R3.2)
/STM32H7S3I8T6/FMC_A2_R: IC5.31 (PC3), RN6.5 (R4.2)
/STM32H7S3I8T6/FMC_A3_R: IC5.46 (PC4), RN8.8 (R1.2)
/STM32H7S3I8T6/FMC_A4_R: IC5.54 (PE7), RN4.8 (R1.2)
/STM32H7S3I8T6/FMC_A5_R: IC5.47 (PC5), RN8.7 (R2.2)
/STM32H7S3I8T6/FMC_A6_R: IC5.124 (PD0), RN10.3 (R3.1)
/STM32H7S3I8T6/FMC_A7_R: IC5.125 (PD1), RN10.2 (R2.1)
/STM32H7S3I8T6/FMC_A8_R: IC5.158 (PF0), RN3.4 (R4.1)
/STM32H7S3I8T6/FMC_A9_R: IC5.159 (PF1), RN3.3 (R3.1)
/STM32H7S3I8T6/FMC_A10_R: IC5.160 (PF2), RN3.2 (R2.1)
/STM32H7S3I8T6/FMC_A11_R: IC5.161 (PF3), RN3.1 (R1.1)
/STM32H7S3I8T6/FMC_A12_R: IC5.55 (PE8), RN4.7 (R2.2)
/STM32H7S3I8T6/FMC_ALE_R: IC5.18 (PF6), RN5.5 (R4.2)
/STM32H7S3I8T6/FMC_BA0_R: IC5.56 (PE9), RN4.6 (R3.2)
/STM32H7S3I8T6/FMC_BA1_R: IC5.57 (PE10), RN4.5 (R4.2)
/STM32H7S3I8T6/FMC_CLE_R: IC5.17 (PF5), RN5.7 (R2.2)
/STM32H7S3I8T6/FMC_D0_R: IC5.113 (PA12), RN10.4 (R4.1)
/STM32H7S3I8T6/FMC_D1_R: IC5.112 (PA11), RN9.1 (R1.1)
/STM32H7S3I8T6/FMC_D2_R: IC5.111 (PA10), RN9.2 (R2.1)
/STM32H7S3I8T6/FMC_D3_R: IC5.110 (PA9), RN9.3 (R3.1)
/STM32H7S3I8T6/FMC_D4_R: IC5.109 (PA8), RN9.4 (R4.1)
/STM32H7S3I8T6/FMC_D5_R: IC5.38 (PA2), RN7.6 (R3.2)
/STM32H7S3I8T6/FMC_D6_R: IC5.37 (PA1), RN7.7 (R2.2)
/STM32H7S3I8T6/FMC_D7_R: IC5.36 (PA0), RN7.8 (R1.2)
/STM32H7S3I8T6/FMC_D8_R: IC5.156 (PD7), RN14.1 (R1.1)
/STM32H7S3I8T6/FMC_D9_R: IC5.170 (PE0), RN2.4 (R4.1)
/STM32H7S3I8T6/FMC_D10_R: IC5.171 (PE1), RN2.3 (R3.1)
/STM32H7S3I8T6/FMC_D11_R: IC5.172 (PE2), RN2.2 (R2.1)
/STM32H7S3I8T6/FMC_D12_R: IC5.7 (PE3), RN1.8 (R1.2)
/STM32H7S3I8T6/FMC_D13_R: IC5.8 (PE4), RN1.7 (R2.2)
/STM32H7S3I8T6/FMC_D14_R: IC5.9 (PE5), RN1.6 (R3.2)
/STM32H7S3I8T6/FMC_D15_R: IC5.10 (PE6), RN1.5 (R4.2)
/STM32H7S3I8T6/FMC_NCE_R: IC5.154 (PD5), RN13.2 (R2.1)
/STM32H7S3I8T6/FMC_NOE_R: IC5.49 (PB1), RN8.6 (R3.2)
/STM32H7S3I8T6/FMC_NWE_R: IC5.50 (PB2), RN8.5 (R4.2)
/STM32H7S3I8T6/PB0_GFXTIM_TE_R: IC5.48 (PB0), RN13.1 (R1.1)
/STM32H7S3I8T6/PC13_R: IC5.2 (PC13), RN13.3 (R3.1)
/STM32H7S3I8T6/PC14-OSC32_IN: IC5.3 (PC14-OSC32_IN), R20.2
/STM32H7S3I8T6/PD6_FMC_NE3_R: IC5.155 (PD6), RN14.2 (R2.1)
/STM32H7S3I8T6/PD8_FMC_NBL0_R: IC5.83 (PD8), RN11.8 (R1.2)
/STM32H7S3I8T6/PD9_FMC_SDCLK_R: IC5.84 (PD9), RN11.6 (R3.2)
/STM32H7S3I8T6/PE11_FMC_SDNWE_R: IC5.127 (PE11), RN10.1 (R1.1)
/STM32H7S3I8T6/PE12_FMC_SDNRAS_R: IC5.128 (PE12), RN16.4 (R4.1)
/STM32H7S3I8T6/PE13_FMC_SDNCAS_R: IC5.129 (PE13), RN16.3 (R3.1)
/STM32H7S3I8T6/PE14_FMC_SDNE0_R: IC5.130 (PE14), RN16.2 (R2.1)
/STM32H7S3I8T6/PE15_FMC_SDCKE0_R: IC5.131 (PE15), RN16.1 (R1.1)
/STM32H7S3I8T6/PH0-OSC_IN: IC5.23 (PH0-OSC_IN), R21.2
/STM32H7S3I8T6/VDDA_FB: C94.1, C97.1, FB1.2, IC5.34 (VREFP), IC5.35 (VDDA)
GND: C1.1, C5.1, C6.1, C7.1, C8.2, C9.2, C11.2, C12.2, C13.2, C14.2, C15.2, C16.2, C17.2, C19.2, C22.2, C26.1, C46.2, C49.2, C57.2, C86.2, C88.2, C90.1, C91.2, C93.2, C94.2, C95.2, C97.2, C98.2, C101.2, C102.2, C103.2, C104.2, C105.2, C108.2, C109.1, C111.1, C114.2, C115.2, C120.2, C121.2, C122.2, D1.2 (A), H1.1, H2.1, H3.1, H4.1, IC1.13 (VSS_1), IC1.25 (VSS_2), IC1.36 (VSS_3), IC1.38 (PT), IC1.48 (VSS_4), IC5.6 (VSS_1), IC5.11 (VSS_2), IC5.13 (VSSSMPS), IC5.15 (VDDSMPS), IC5.16 (VFBSMPS), IC5.26 (VSS_3), IC5.32 (VSSA), IC5.33 (VREFM), IC5.40 (VSS_4), IC5.52 (VSS_5), IC5.60 (VSS_6), IC5.64 (VSS_7), IC5.68 (VSS_8), IC5.74 (VSS_9), IC5.80 (VSS_10), IC5.88 (VSS_11), IC5.98 (VSS_12), IC5.108 (VSS_13), IC5.118 (VSS_14), IC5.132 (VSS_15), IC5.142 (VSSUSB), IC5.167 (VSS_16), J1.3, J1.6, J1.9, J1.12, J1.15, J1.18, J1.21, J1.24, J1.27, J1.34, J1.35, J1.37, J1.40, J1.43, J1.46, J1.49, J1.52, J1.55, J1.58, J1.SH1, J1.SH2, J3.1, J3.5, J3.7, J9.4, J9.6, J9.7, J9.9, J9.11, J9.13, J9.15, J9.17, J9.21, J9.23, J9.25, J9.26, J9.28, J9.32, J9.34, J9.36, J9.38, J9.39, J9.41, J9.42, J9.44, J9.45, J9.47, J9.48, J9.49, J9.50, J9.51, J9.53, J9.54, J9.55, J9.57, J9.SH1, J9.SH2, J22.A1 (GND), J22.A12 (GND), J22.B1 (GND), J22.B12 (GND), J22.S1 (SHIELD), JST1.2 (PWR-), OS3.2 (GND), R1.2, R4.2, R7.2, R15.2, R16.2, SDRAM1.6 (VSSQ_1), SDRAM1.12 (VSSQ_2), SDRAM1.28 (VSS_1), SDRAM1.41 (VSS_2), SDRAM1.46 (VSSQ_3), SDRAM1.52 (VSSQ_4), SDRAM1.54 (VSS_3), SMPS1.8 (GND), SMPS1.11 (PAD), U1.1, U1.2, U7.2 (GND), Y1.2 (GND/CASE)
unnamed: J22.A5 (CC1), R15.1
unnamed: J22.B5 (CC2), R16.1
unnamed: OS3.3 (OUTPUT), R20.1
unnamed: R21.1, Y1.3 (OUTPUT)
PWR_D+: C6.2, D1.1 (K), J2.2, SMPS1.2 (MODE_DATA), SMPS1.3 (VIN), SMPS1.7 (EN1), SMPS1.9 (EN2)
SMPS_OUT1_1V2+: C7.2, C9.1, C22.1, C57.1, C104.1, IC5.59 (VDDLDO_1), IC5.61 (VCAP1), IC5.97 (VCAP2), IC5.99 (VDDLDO_2), IC5.117 (VCAP3), IC5.119 (VDDLDO_3), IC5.166 (VCAP4), IC5.168 (VDDLDO_4), L1.2, R3.1, SMPS1.4 (FB1)
SMPS_OUT2_3V3+: C8.1, C11.1, C12.1, C13.1, C14.1, C15.1, C16.1, C17.1, C19.1, C26.2, C27.2, C46.1, C49.1, C86.1, C88.1, C90.2, C91.1, C93.1, C95.1, C98.1, C101.1, C102.1, C103.1, C105.1, C108.1, C109.2, C111.2, C114.1, C115.1, C120.1, C121.1, C122.1, FB1.1, IC1.12 (VCC_1), IC1.34 (VCC_2), IC1.37 (VCC_3), IC1.39 (VCC_4), IC5.1 (VBAT), IC5.5 (VDD_1), IC5.12 (VDD_2), IC5.27 (VDD_3), IC5.41 (VDD_4), IC5.51 (VDD_5), IC5.58 (VDD_6), IC5.63 (VDDXSPI1_1), IC5.69 (VDDXSPI1_2), IC5.75 (VDDXSPI1_3), IC5.81 (VDDXSPI1_4), IC5.87 (VDD_7), IC5.100 (VDD_8), IC5.107 (VDD_9), IC5.120 (VDD_10), IC5.133 (VDD_11), IC5.140 (VDD50USB), IC5.141 (VDD33USB), IC5.145 (DVDD), IC5.148 (VDD_12), IC5.157 (VDD_13), IC5.169 (VDD_14), J1.31, J1.32, J1.33, J3.3, J9.18, J9.19, J9.20, L5.2, OS3.1 (TRI-STATE), OS3.4 (VDD), R5.1, R9.2, R13.1, SDRAM1.1 (VDD_1), SDRAM1.3 (VDDQ_1), SDRAM1.9 (VDDQ_2), SDRAM1.14 (VDD_2), SDRAM1.27 (VDD_3), SDRAM1.43 (VDDQ_3), SDRAM1.49 (VDDQ_4), Y1.4 (VDD)
USB_VBUS+: J2.1, J22.A4 (VBUS), J22.A9 (VBUS), J22.B4 (VBUS), J22.B9 (VBUS), U7.5 (VBUS)

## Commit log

2026-03-17 Pin typo fix
    [Interface_Headers.kicad_sch, STM32H7S3I8T6.kicad_sch, STM32H7_Board.kicad_pcb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]
2026-03-25 Added I2C to the LCD interface
    [Interface_Headers.kicad_sch, LCD.kicad_sch, STM32H7S3I8T6.kicad_sch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]
2026-03-25 General PCB tweaks
    [STM32H7_Board.kicad_pcb]
2026-05-13 NAND Interface
    [Memory.kicad_sch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]
2026-07-03 Updated Schematics Sheets
